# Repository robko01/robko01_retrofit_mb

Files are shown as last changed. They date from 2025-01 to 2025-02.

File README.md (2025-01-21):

# robko01_retrofit_mb

 - **BOM**

|Id |Designator |Footprint |Quantity|Designation |Supplier and ref|FIELD7|FIELD8|
|---|---|---|---|---|---|---|---|
|1  |D3,D4 |LED_D5.0mm |2 |LED | | | |
|2  |SW2,SW1,SW5,SW7,SW3,SW4|DIP-8_W7.62mm |6 |SW_DIP_x04 | | | |
|3  |C9,C13,C11,C7,C3,C5 |C_Disc_D7.0mm_W2.5mm_P5.00mm |6 |100n | | | |
|4  |C4,C10,C12,C6,C14,C8 |CP_Radial_D8.0mm_P3.50mm |6 |100u | | | |
|5  |J18,J20,J19,J30,J17,J31|PinHeader_1x02_P2.54mm_Vertical |6 |Conn_01x02_Male | | | |
|6  |A1,A4,A2,A6,A5,A3 |Pololu_Breakout-16_15.2x20.3mm |6 |Pololu_Breakout_A4988| | | |
|7  |D2,D1 |D_DO-41_SOD81_P10.16mm_Horizontal |2 |1N4007 | | | |
|8  |R1 |R_Axial_DIN0207_L6.3mm_D2.5mm_P10.16mm_Horizontal |1 |2k | | | |
|9  |K2 |Relay_DPDT_Omron_G5V-2 |1 |G5V-2 | | | |
|10 |J21,J22 |PinSocket_1x19_P2.54mm_Vertical |2 |Conn_01x19_Pin | | | |
|11 |J14,J1,J4,J16,J12,J6 |PinHeader_1x04_P2.54mm_Vertical |6 |Conn_01x04_Pin | | | |
|12 |J10,J11,J9 |PinHeader_1x13_P2.54mm_Vertical |3 |Motors | | | |
|13 |J28,J7 |PhoenixContact_MSTBA_2,5_2-G-5,08_1x02_P5.08mm_Horizontal |2 |Conn_01x02_Male | | | |
|14 |F1 |Fuseholder_Clip-5x20mm_Bel_FC-203-22_Lateral_P17.80x5.00mm_D1.17mm_Horizontal|1 |Fuse | | | |
|15 |J19,J20 |PinHeader_1x01_P2.54mm_Vertical |2 |Conn_01x01_Pin | | | |
|16 |J24,J25,J26 |PinHeader_1x04_P2.54mm_Horizontal |3 |Conn_01x04_Pin | | | |
|17 |J15,J2,J5,J13,J8,J3 |PinHeader_1x02_P2.54mm_Vertical |6 |Conn_01x02_Pin | | | |
|18 |J29 |PinHeader_1x07_P2.54mm_Horizontal |1 |Conn_01x07_Pin | | | |
|19 |J27,J23 |PinHeader_1x06_P2.54mm_Horizontal |2 |Conn_01x06_Pin | | | |
|20|(J21 and J22)|ESP32-WROOM-32D|1|Main CPI board.|
|21|(J17,J18,J19,J20,J31)|MP1584EN|1|Low voltage DC/DC convertor.|

 - **Pinmap**

| Function | ESP32 | Direction | C Code |
|---|:---|:---|----|
| Enable Motors | GPIO2 | OUTPUT | ```#define MX_ENB 2```|
| Motor 1 Direction | GPIO4 | OUTPUT | ```#define M1_DIR 4```|
| Motor 1 Step | GPIO0 | OUTPUT | ```#define M1_STP 0```|
| Motor 2 Direction | GPIO17 | OUTPUT | ```#define M2_DIR 17```|
| Motor 2 Step | GPIO16 | OUTPUT | ```#define M2_STP 16```|
| Motor 3 Direction | GPIO25 | OUTPUT | ```#define M3_DIR 12```|
| Motor 3 Step | GPIO26 | OUTPUT | ```#define M3_STP 13```|
| Motor 4 Direction | GPIO12 | OUTPUT | ```#define M4_DIR 27```|
| Motor 4 Step | GPIO13 | OUTPUT | ```#define M4_STP 14```|
| Motor 5 Direction | GPIO27 | OUTPUT | ```#define M5_DIR 25```|
| Motor 5 Step | GPIO14 | OUTPUT | ```#define M5_STP 26```|
| Motor 6 Direction | GPIO32 | OUTPUT | ```#define M6_DIR 32```|
| Motor 6 Step | GPIO33 | OUTPUT | ```#define M6_STP 33```|
| Motor 1 Limit | GPIO36 | INPUT | ```#define M1_LIMIT 36```|
| Motor 2 Limit | GPIO39 | INPUT | ```#define M2_LIMIT 39```|
| Motor 3 Limit | GPIO34 | INPUT | ```#define M3_LIMIT 34```|
| Motor 6 Limit | GPIO35 | INPUT | ```#define M6_LIMIT 35```|
| E-Stop | GPIO15 | INPUT_PULLUP | ```#define E_STOP 35```|

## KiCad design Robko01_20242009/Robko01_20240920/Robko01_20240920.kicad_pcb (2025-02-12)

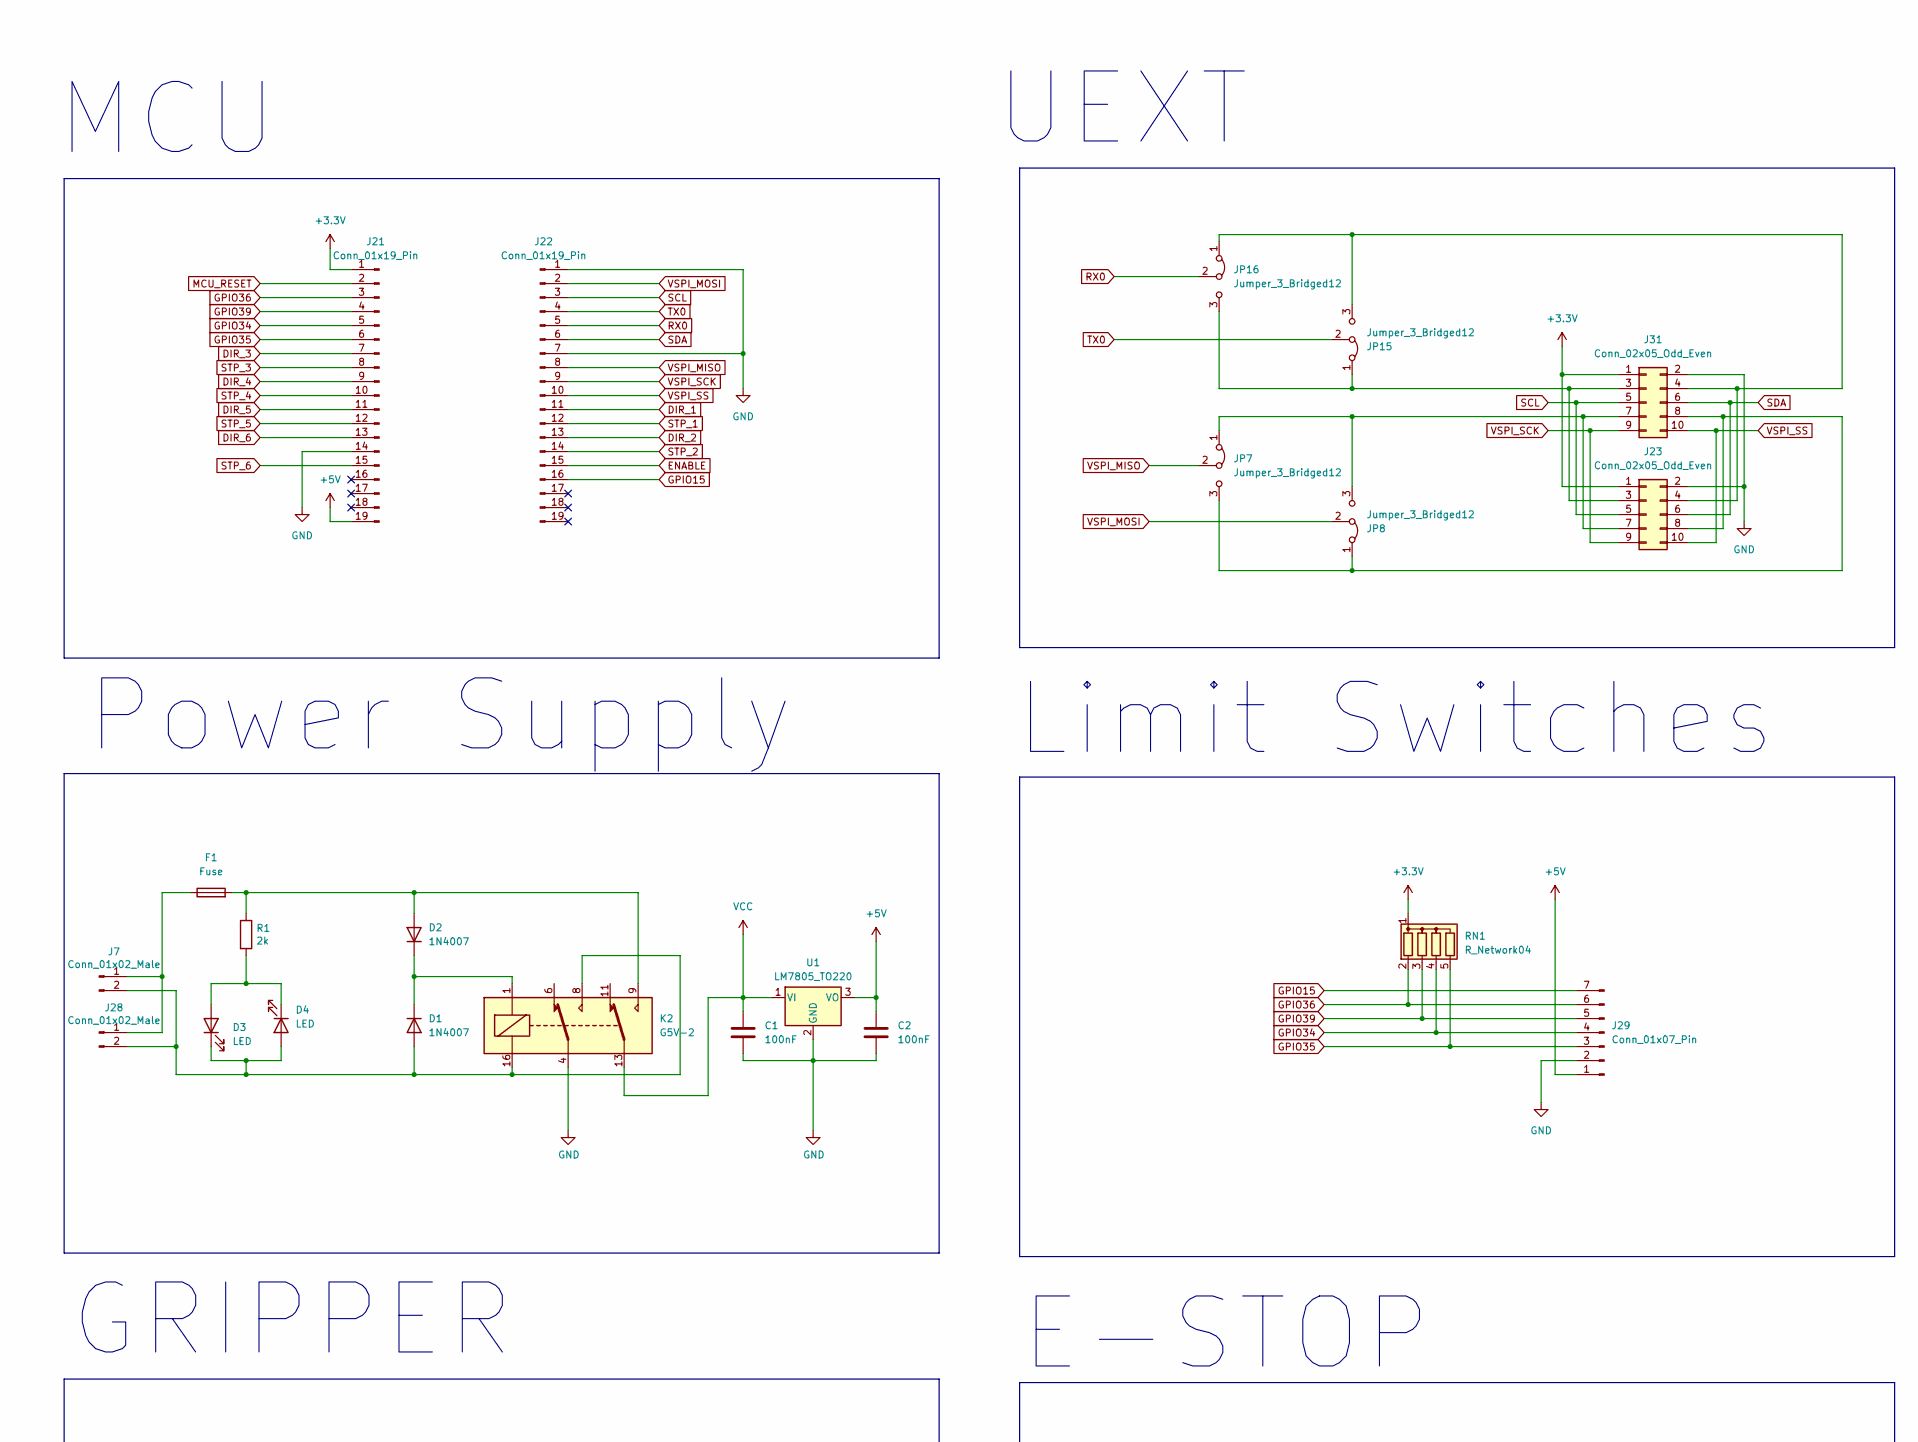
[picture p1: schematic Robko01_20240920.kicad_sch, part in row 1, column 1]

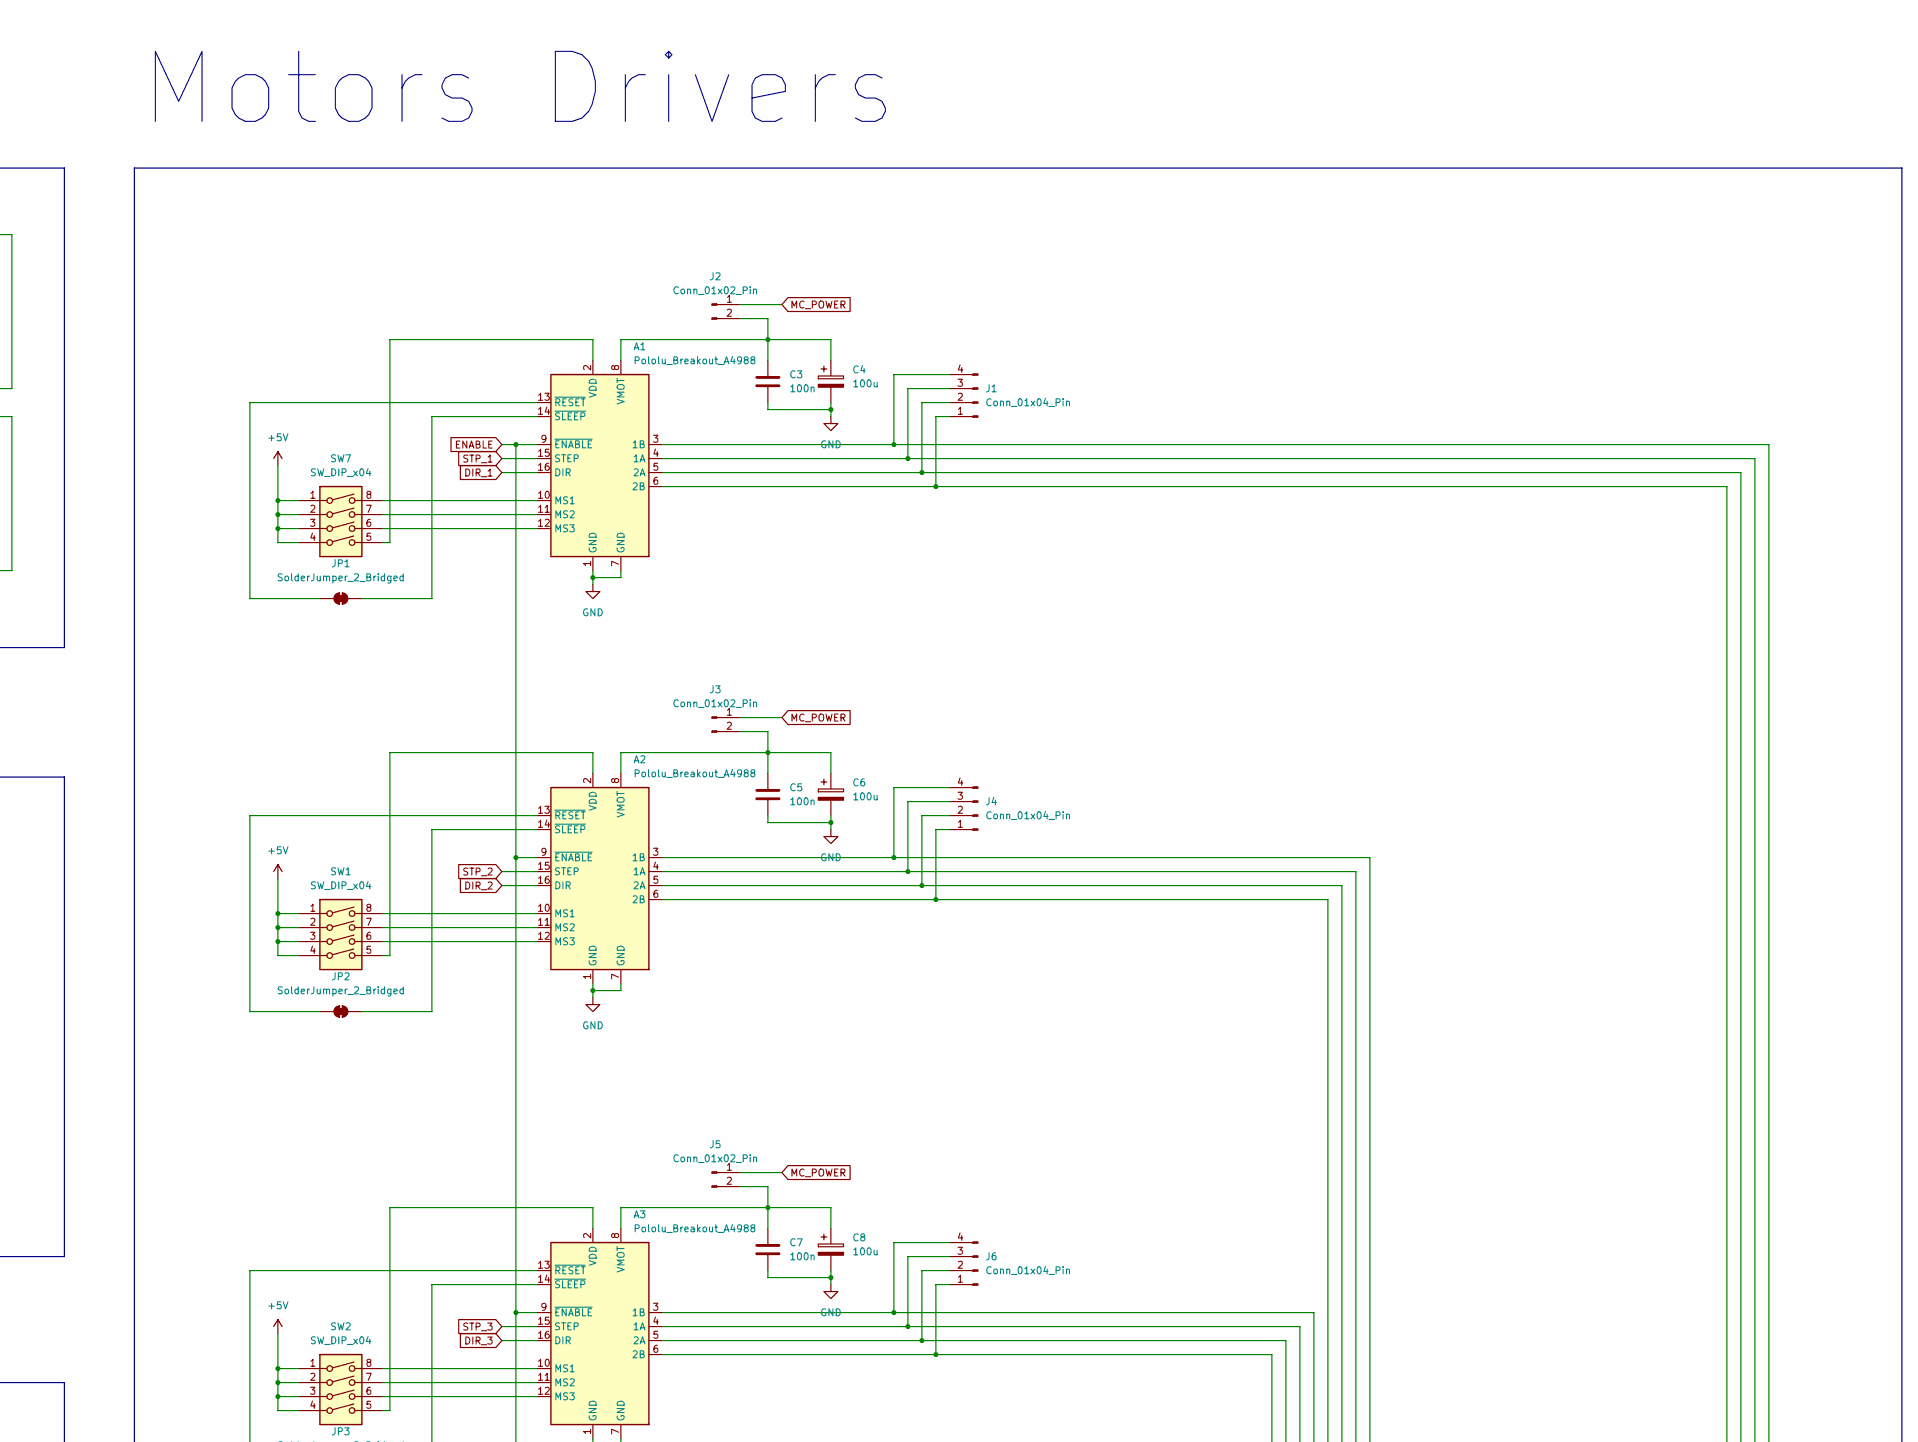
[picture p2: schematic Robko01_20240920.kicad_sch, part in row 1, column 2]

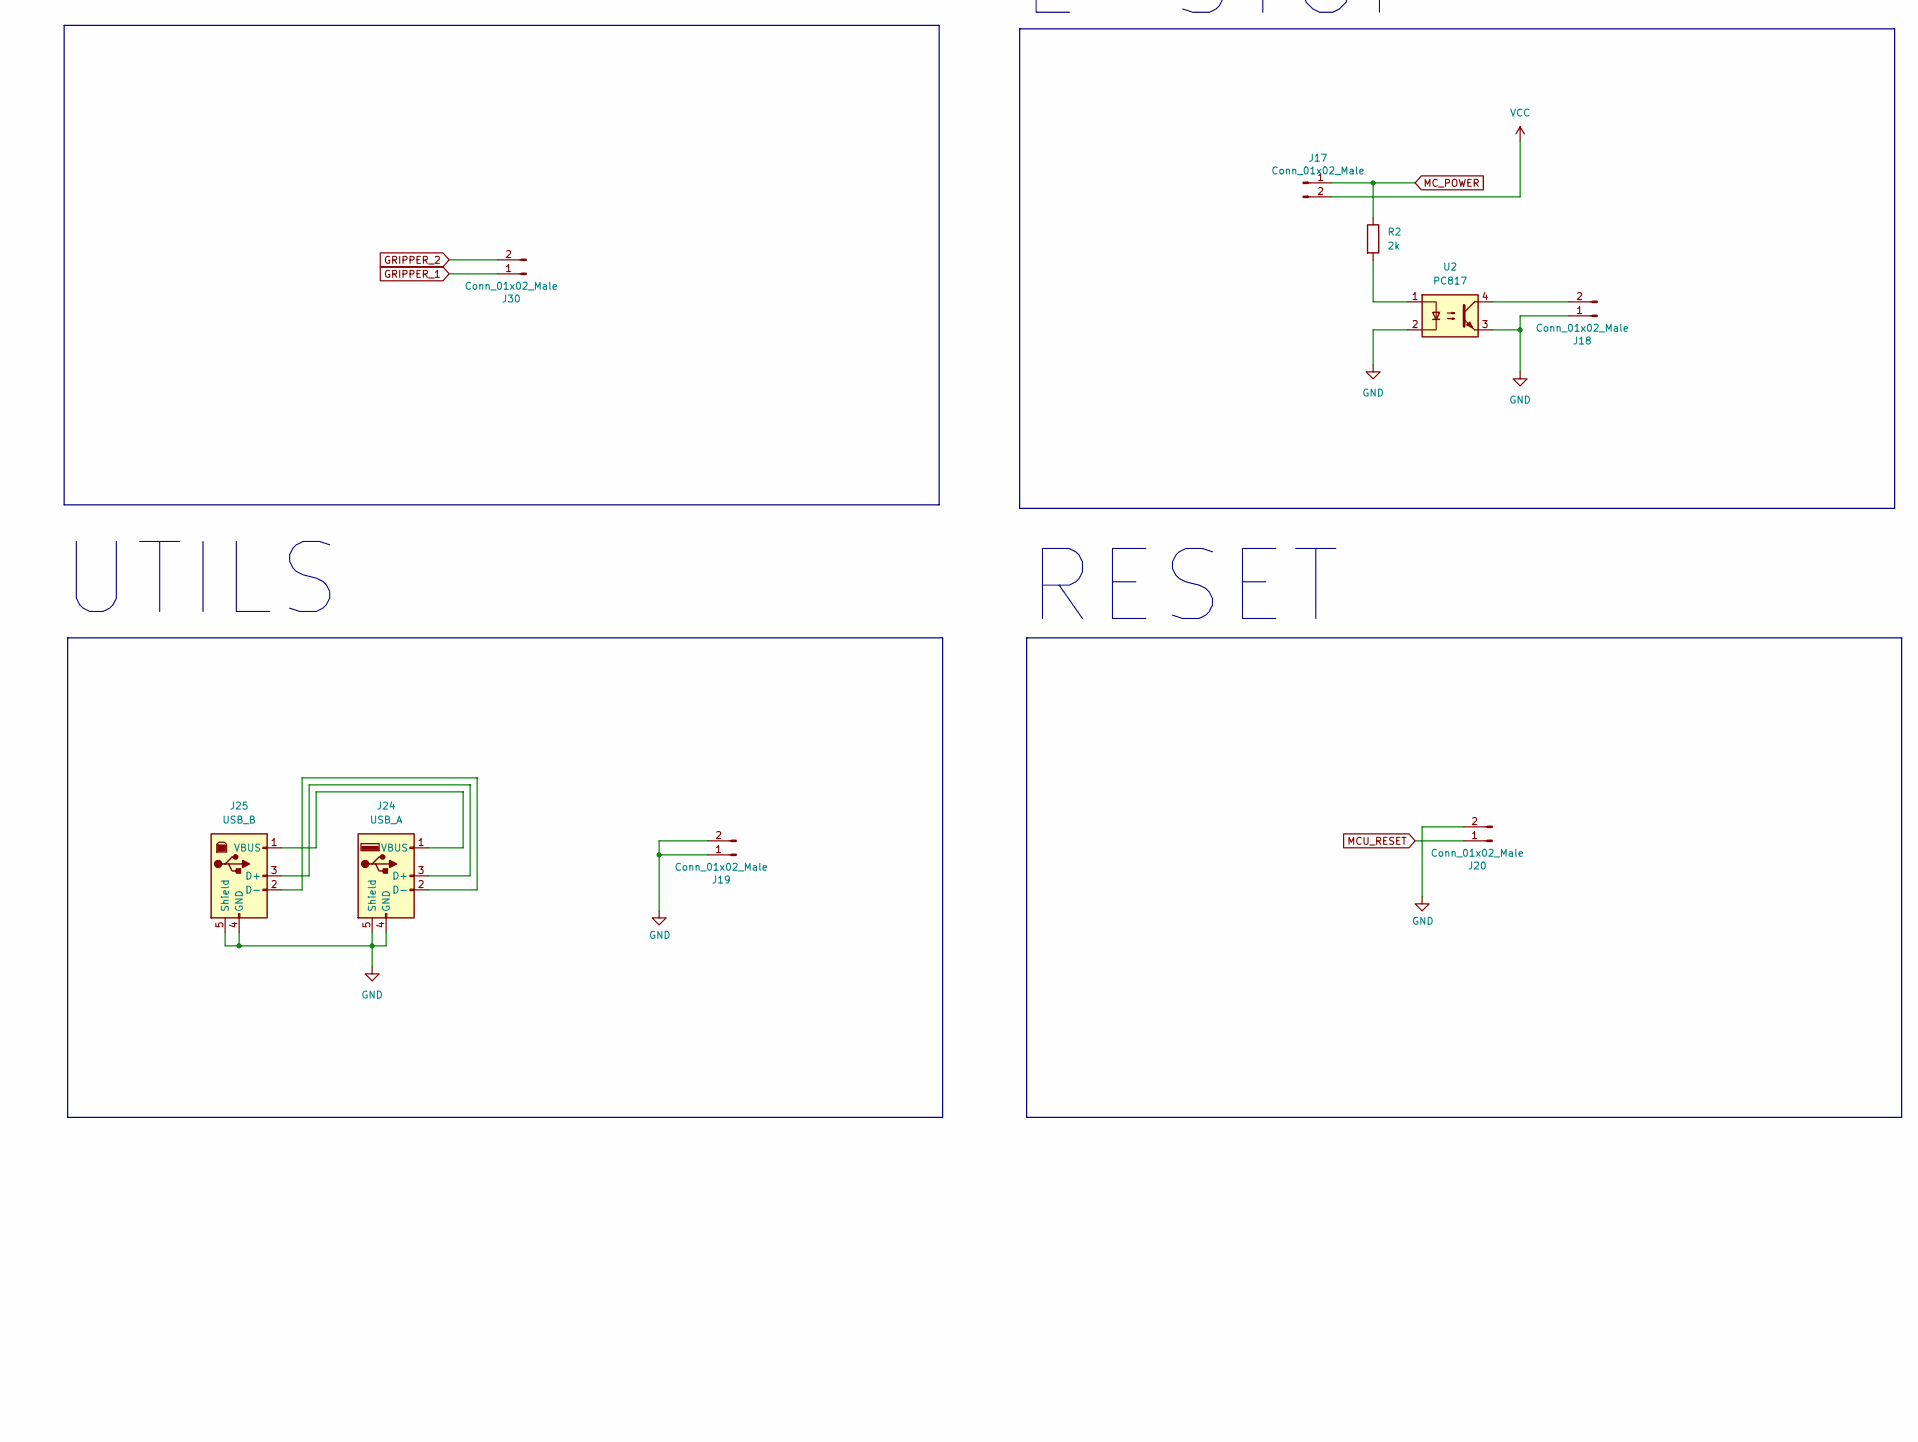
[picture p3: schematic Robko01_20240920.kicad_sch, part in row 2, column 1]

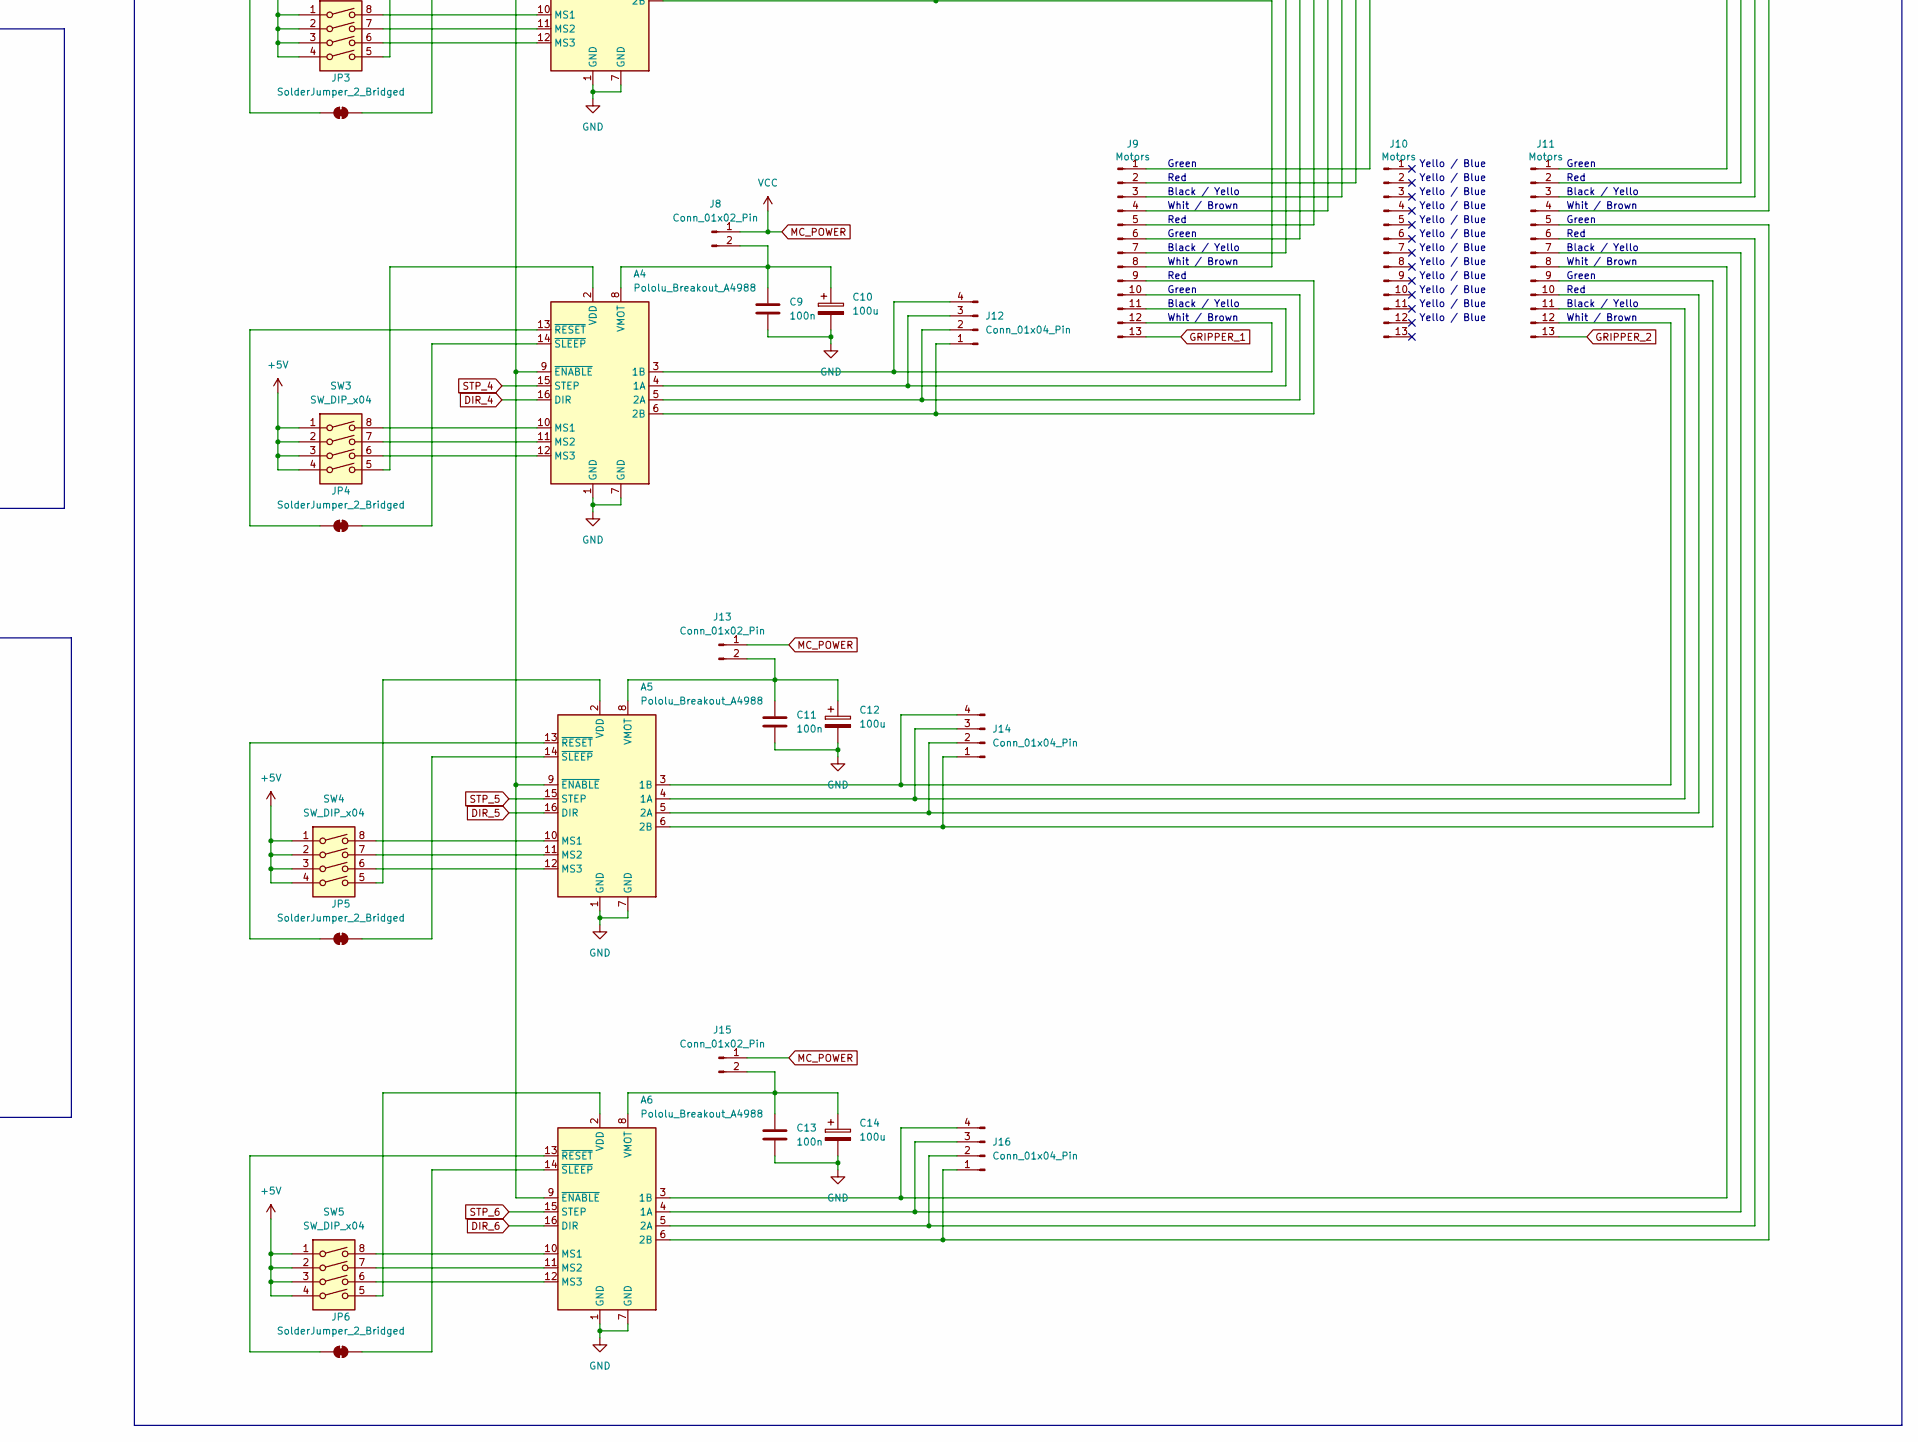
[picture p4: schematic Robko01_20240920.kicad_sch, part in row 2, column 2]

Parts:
A1, A2, A3, A4, A5, A6: Pololu_Breakout_A4988; Pololu_Breakout-16_15.2x20.3mm
C1, C2: 100nF; C_Disc_D7.5mm_W2.5mm_P5.00mm
C3, C5, C7, C9, C11, C13: 100n; C_Disc_D7.0mm_W2.5mm_P5.00mm
C4, C6, C8, C10, C12, C14: 100u; CP_Radial_D8.0mm_P3.50mm
D1, D2: 1N4007; D_DO-41_SOD81_P10.16mm_Horizontal
D3, D4: LED; LED_D5.0mm
F1: Fuse; Fuseholder_Clip-5x20mm_Bel_FC-203-22_Lateral_P17.80x5.00mm_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
J1, J4, J6, J12, J14, J16: Conn_01x04_Pin; PinHeader_1x04_P2.54mm_Horizontal
J2, J3, J5, J8, J13, J15: Conn_01x02_Pin; PinHeader_1x02_P2.54mm_Vertical
J7, J17, J28: Conn_01x02_Male; PhoenixContact_MSTBA_2,5_2-G-5,08_1x02_P5.08mm_Horizontal
J9, J10, J11: Motors; PinHeader_1x13_P2.54mm_Vertical
J18, J20, J30: Conn_01x02_Male; PinHeader_1x02_P2.54mm_Horizontal
J19: Conn_01x02_Male; PinHeader_1x02_P2.54mm_Vertical
J21, J22: Conn_01x19_Pin; PinSocket_1x19_P2.54mm_Vertical
J23, J31: Conn_02x05_Odd_Even; IDC-Header_2x05_P2.54mm_Horizontal
J24: USB_A; USB_A_Molex_67643_Horizontal
J25: USB_B; USB_B_Lumberg_2411_02_Horizontal
J29: Conn_01x07_Pin; PinHeader_1x07_P2.54mm_Horizontal
JP1, JP2, JP3, JP4, JP5, JP6: SolderJumper_2_Bridged; SolderJumper-2_P1.3mm_Bridged2Bar_RoundedPad1.0x1.5mm
JP7, JP8, JP15, JP16: Jumper_3_Bridged12; SolderJumper-3_P1.3mm_Bridged2Bar12_Pad1.0x1.5mm
K2: G5V-2; Relay_DPDT_Omron_G5V-2
R1, R2: 2k; R_Axial_DIN0207_L6.3mm_D2.5mm_P10.16mm_Horizontal
RN1: R_Network04; R_Array_SIP5
SW1, SW2, SW3, SW4, SW5, SW7: SW_DIP_x04; DIP-8_W7.62mm
U1: LM7805_TO220; TO-220F-3_Horizontal_TabDown
U2: PC817; DIP-4_W7.62mm

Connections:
+3.3V: J21.1, J23.1, J31.1, RN1.1 (common)
+5V: C2.1, J21.19, J29.1, SW1.1, SW1.2, SW1.3, SW1.4, SW2.1, SW2.2, SW2.3, SW2.4, SW3.1, SW3.2, SW3.3, SW3.4, SW4.1, SW4.2, SW4.3, SW4.4, SW5.1, SW5.2, SW5.3, SW5.4, SW7.1, SW7.2, SW7.3, SW7.4, U1.3 (VO)
DIR_1: A1.16 (DIR), J22.11
DIR_2: A2.16 (DIR), J22.13
DIR_3: A3.16 (DIR), J21.7
DIR_4: A4.16 (DIR), J21.9
DIR_5: A5.16 (DIR), J21.11
DIR_6: A6.16 (DIR), J21.13
ENABLE: A1.9 (~ENABLE), A2.9 (~ENABLE), A3.9 (~ENABLE), A4.9 (~ENABLE), A5.9 (~ENABLE), A6.9 (~ENABLE), J22.15
GND: A1.1 (GND), A1.7 (GND), A2.1 (GND), A2.7 (GND), A3.1 (GND), A3.7 (GND), A4.1 (GND), A4.7 (GND), A5.1 (GND), A5.7 (GND), A6.1 (GND), A6.7 (GND), C1.2, C2.2, C3.2, C4.2, C5.2, C6.2, C7.2, C8.2, C9.2, C10.2, C11.2, C12.2, C13.2, C14.2, J18.1, J19.1, J19.2, J20.2, J21.14, J22.1, J22.7, J23.2, J24.4 (GND), J24.5 (Shield), J25.4 (GND), J25.5 (Shield), J29.2, J31.2, K2.4, U1.2 (GND), U2.2, U2.3
GPIO15: J22.16, J29.7
GPIO34: J21.5, J29.4, RN1.4 (R3)
GPIO35: J21.6, J29.3, RN1.5 (R4)
GPIO36: J21.3, J29.6, RN1.2 (R1)
GPIO39: J21.4, J29.5, RN1.3 (R2)
GRIPPER_1: J9.13, J30.1
GRIPPER_2: J11.13, J30.2
MCU_RESET: J20.1, J21.2
MC_POWER: C1.1, J2.1, J3.1, J5.1, J8.1, J13.1, J15.1, J17.1, J17.2, K2.13, R2.1, U1.1 (VI)
unnamed: A1.4 (1A), J1.3, J11.3
unnamed: A1.3 (1B), J1.4, J11.4
unnamed: A1.5 (2A), J1.2, J11.2
unnamed: A1.6 (2B), J1.1, J11.1
unnamed: A1.10 (MS1), SW7.8
unnamed: A1.11 (MS2), SW7.7
unnamed: A1.12 (MS3), SW7.6
unnamed: A1.2 (VDD), SW7.5
unnamed: A1.8 (VMOT), C3.1, C4.1, J2.2
unnamed: A1.13 (~RESET), JP1.1 (A)
unnamed: A1.14 (~SLEEP), JP1.2 (B)
unnamed: A2.4 (1A), J4.3, J9.2
unnamed: A2.3 (1B), J4.4, J9.1
unnamed: A2.5 (2A), J4.2, J9.3
unnamed: A2.6 (2B), J4.1, J9.4
unnamed: A2.10 (MS1), SW1.8
unnamed: A2.11 (MS2), SW1.7
unnamed: A2.12 (MS3), SW1.6
unnamed: A2.2 (VDD), SW1.5
unnamed: A2.8 (VMOT), C5.1, C6.1, J3.2
unnamed: A2.13 (~RESET), JP2.1 (A)
unnamed: A2.14 (~SLEEP), JP2.2 (B)
unnamed: A3.4 (1A), J6.3, J9.6
unnamed: A3.3 (1B), J6.4, J9.5
unnamed: A3.5 (2A), J6.2, J9.7
unnamed: A3.6 (2B), J6.1, J9.8
unnamed: A3.10 (MS1), SW2.8
unnamed: A3.11 (MS2), SW2.7
unnamed: A3.12 (MS3), SW2.6
unnamed: A3.2 (VDD), SW2.5
unnamed: A3.8 (VMOT), C7.1, C8.1, J5.2
unnamed: A3.13 (~RESET), JP3.1 (A)
unnamed: A3.14 (~SLEEP), JP3.2 (B)
unnamed: A4.4 (1A), J9.11, J12.3
unnamed: A4.3 (1B), J9.12, J12.4
unnamed: A4.5 (2A), J9.10, J12.2
unnamed: A4.6 (2B), J9.9, J12.1
unnamed: A4.10 (MS1), SW3.8
unnamed: A4.11 (MS2), SW3.7
unnamed: A4.12 (MS3), SW3.6
unnamed: A4.2 (VDD), SW3.5
unnamed: A4.8 (VMOT), C9.1, C10.1, J8.2
unnamed: A4.13 (~RESET), JP4.1 (A)
unnamed: A4.14 (~SLEEP), JP4.2 (B)
unnamed: A5.4 (1A), J11.11, J14.3
unnamed: A5.3 (1B), J11.12, J14.4
unnamed: A5.5 (2A), J11.10, J14.2
unnamed: A5.6 (2B), J11.9, J14.1
unnamed: A5.10 (MS1), SW4.8
unnamed: A5.11 (MS2), SW4.7
unnamed: A5.12 (MS3), SW4.6
unnamed: A5.2 (VDD), SW4.5
unnamed: A5.8 (VMOT), C11.1, C12.1, J13.2
unnamed: A5.13 (~RESET), JP5.1 (A)
unnamed: A5.14 (~SLEEP), JP5.2 (B)
unnamed: A6.4 (1A), J11.7, J16.3
unnamed: A6.3 (1B), J11.8, J16.4
unnamed: A6.5 (2A), J11.6, J16.2
unnamed: A6.6 (2B), J11.5, J16.1
unnamed: A6.10 (MS1), SW5.8
unnamed: A6.11 (MS2), SW5.7
unnamed: A6.12 (MS3), SW5.6
unnamed: A6.2 (VDD), SW5.5
unnamed: A6.8 (VMOT), C13.1, C14.1, J15.2
unnamed: A6.13 (~RESET), JP6.1 (A)
unnamed: A6.14 (~SLEEP), JP6.2 (B)
unnamed: D1.2 (A), D3.1 (K), D4.2 (A), J7.2, J28.2, K2.8, K2.16
unnamed: D1.1 (K), D2.1 (K), K2.1
unnamed: D2.2 (A), F1.2, K2.9, R1.1
unnamed: D3.2 (A), D4.1 (K), R1.2
unnamed: J18.2, U2.4
unnamed: J23.3, J31.3, JP15.1 (A), JP16.3 (B)
unnamed: J23.4, J31.4, JP15.3 (B), JP16.1 (A)
unnamed: J23.7, J31.7, JP7.1 (A), JP8.3 (B)
unnamed: J23.8, J31.8, JP7.3 (B), JP8.1 (A)
unnamed: J24.3 (D+), J25.3 (D+)
unnamed: J24.2 (D-), J25.2 (D-)
unnamed: J24.1 (VBUS), J25.1 (VBUS)
unnamed: F1.1, J7.1, J28.1
unnamed: R2.2, U2.1
RX0: J22.5, JP16.2 (C)
SCL: J22.3, J23.5, J31.5
SDA: J22.6, J23.6, J31.6
STP_1: A1.15 (STEP), J22.12
STP_2: A2.15 (STEP), J22.14
STP_3: A3.15 (STEP), J21.8
STP_4: A4.15 (STEP), J21.10
STP_5: A5.15 (STEP), J21.12
STP_6: A6.15 (STEP), J21.15
TX0: J22.4, JP15.2 (C)
VSPI_MISO: J22.8, JP7.2 (C)
VSPI_MOSI: J22.2, JP8.2 (C)
VSPI_SCK: J22.9, J23.9, J31.9
VSPI_SS: J22.10, J23.10, J31.10

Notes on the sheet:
Yello / Blue
Limit Switches
MCU
Black / Yello
Motors Drivers
Red
Whit / Brown
UTILS
Green
RESET
Power Supply
E-STOP
GRIPPER
UEXT

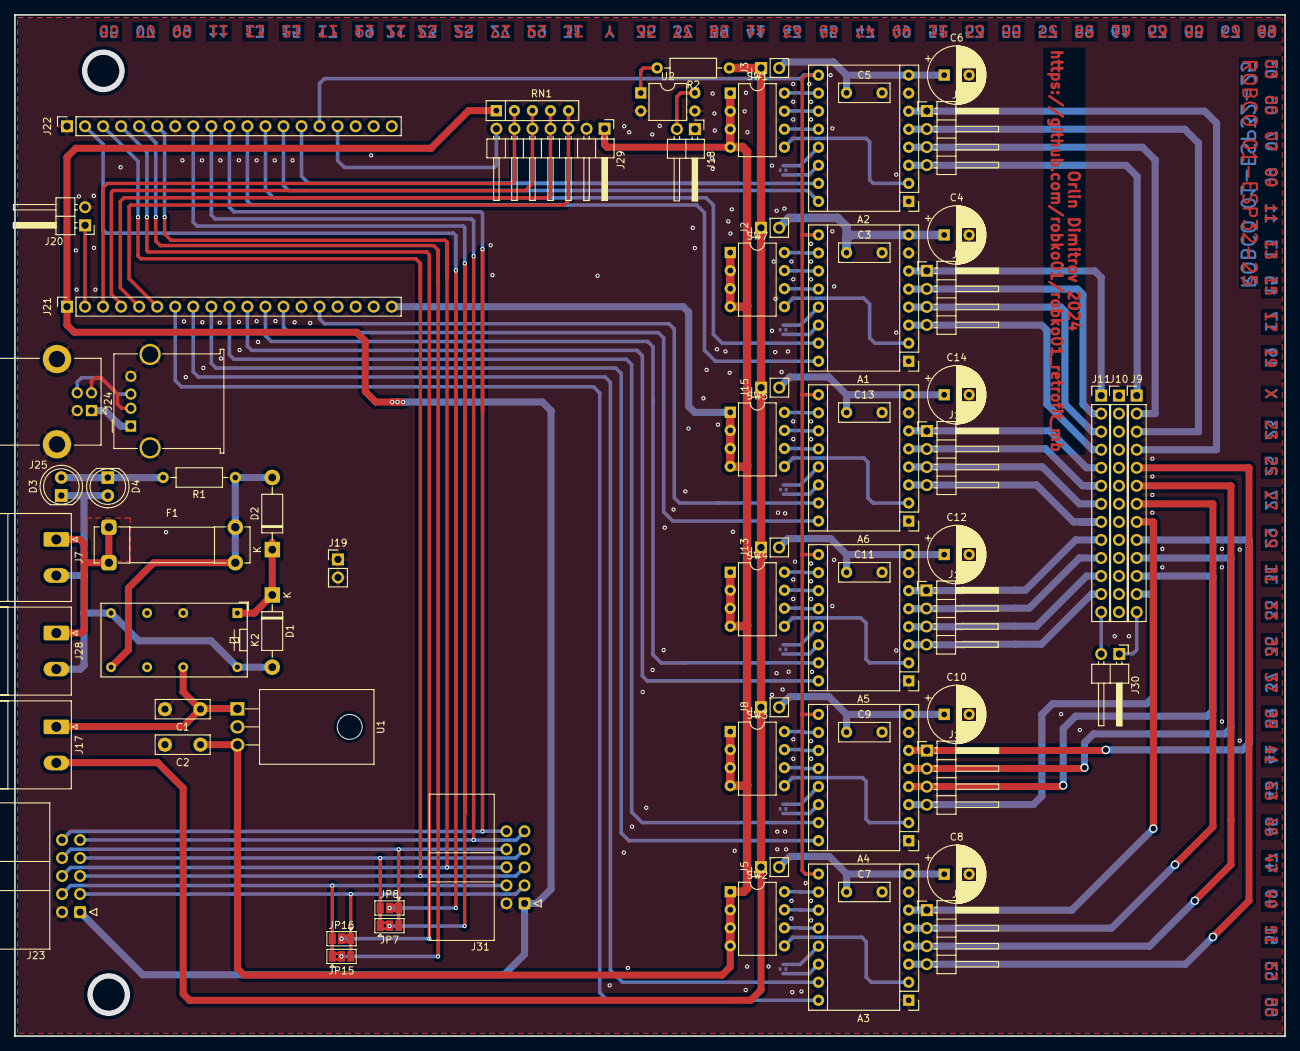
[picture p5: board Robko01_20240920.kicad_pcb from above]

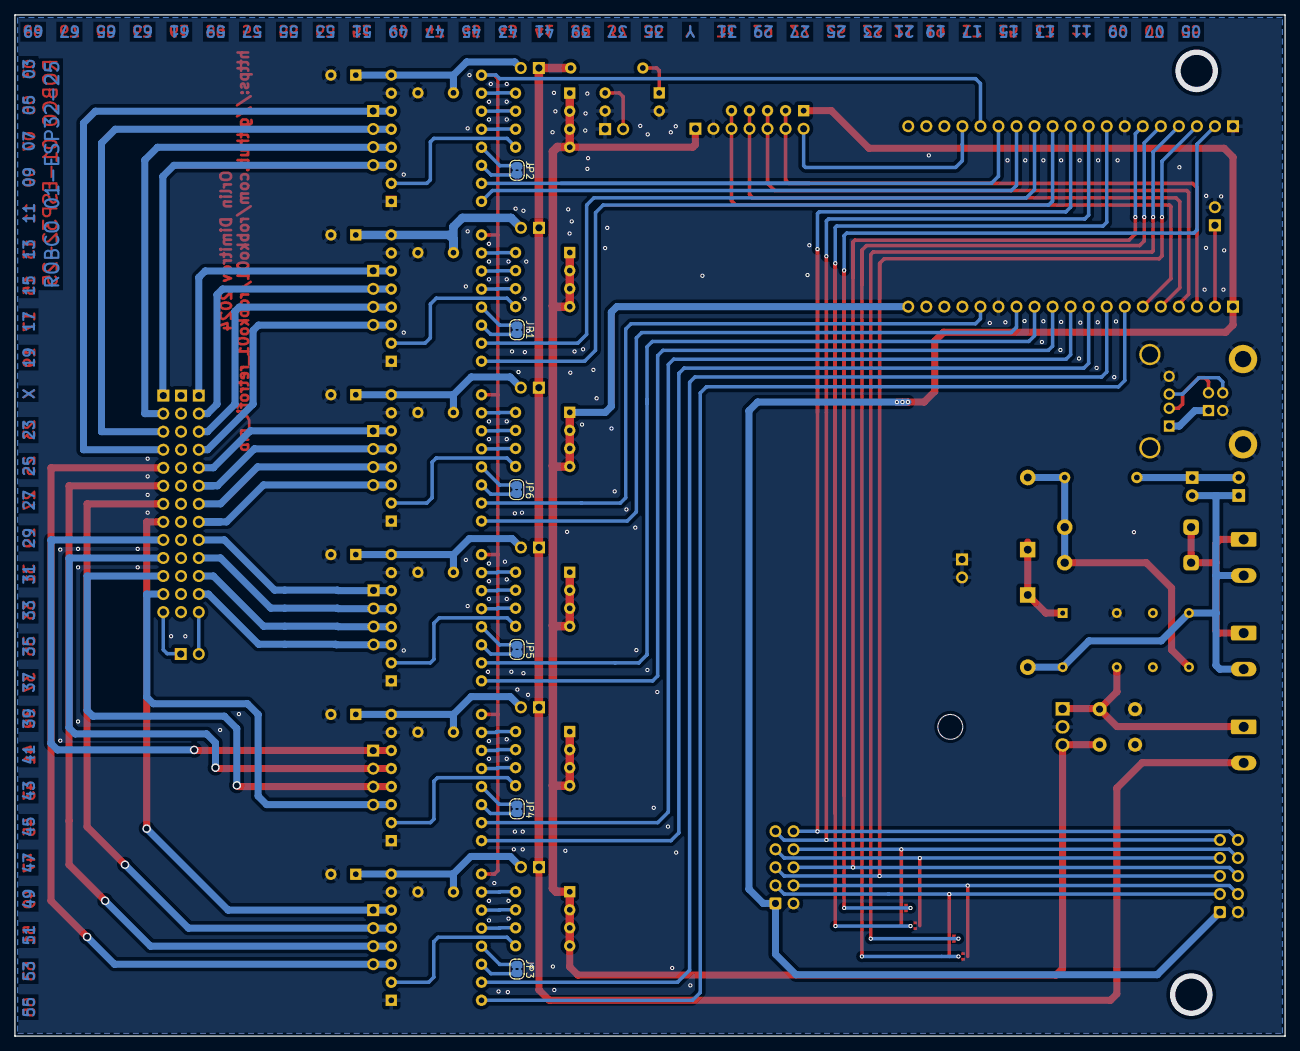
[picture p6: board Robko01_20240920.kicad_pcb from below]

Board: 2 copper layers, 178.8 x 143.8 mm, 76 parts (6 on the bottom side), 113 nets.

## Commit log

2024-10-11 Fix main MCU footprint size
    [Robko01_20240920.kicad_pcb, Robko01_20240920.kicad_sch]
2024-11-08 Add pin mapping
2024-11-08 Fix geometry
    [Robko01_20240920.kicad_pcb, Robko01_20240920.kicad_sch]
2024-11-08 Fix pin mapping
2024-11-09 Relocate elements and fix power connector positions
    [Robko01_20240920.kicad_pcb, Robko01_20240920.kicad_sch]
2024-11-17 Add BOM
    [Robko01_20240920.kicad_pcb, Robko01_20240920.kicad_sch]
2024-12-17 Add small improvements
    [Robko01_20240920.kicad_pcb, Robko01_20240920.kicad_sch]
2024-12-18 Add more improvements
    [Robko01_20240920.kicad_pcb, Robko01_20240920.kicad_sch]
2025-01-11 Add E-Stop
    [Robko01_20240920.kicad_pcb, Robko01_20240920.kicad_sch]
2025-01-20 Add reset button and E-Stop
    [Robko01_20240920.kicad_pcb]
2025-01-24 Add UEXT
    [Robko01_20240920.kicad_pcb, Robko01_20240920.kicad_sch]
2025-01-27 Change jumpers for UEXT
    [Robko01_20240920.kicad_pcb, Robko01_20240920.kicad_sch]
2025-02-03 Add USB
    [Robko01_20240920.kicad_pcb, Robko01_20240920.kicad_sch]
2025-02-12 Update USB imp balance
    [Robko01_20240920.kicad_pcb]
2025-04-30 Change E-Stop connector, add default jumper to power supply of the stepper drivers, wireup limit switch of the gripper, rewire E-Stop sensor
2026-10-12 Ignore generated renders and KiCad local files
2026-10-12 Add downloaded USB-B connector 3D model
2026-10-12 Convert ceramic capacitors to 0805 footprints
2026-10-12 Convert D1 and D2 to SMD and remove obsolete BOM snapshots
2026-10-12 Convert resistors to 0805 and split RN1 into five 10k resistors
2026-10-12 Convert D3 and D4 to 0805 LED footprints
2026-10-12 Include local 3D models for all physical board components
2026-10-12 Document SMD model visibility in KiCad 3D Viewer
2026-10-12 Convert electrolytic capacitors to SMD with local 3D model
